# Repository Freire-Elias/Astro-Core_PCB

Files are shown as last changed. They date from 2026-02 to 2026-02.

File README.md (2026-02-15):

# Astro-Core PCB

Placa de controle baseada em **ESP32**, projetada para a equipe de robótica competitiva OBR **AstroTech**.

---

## What is this project?

This project was designed to create a central module for sensors, control, motors, and monitoring of an OBR robot.
This repository contains all the hardware files (PCB and schematics) for this board.

---

## 3D Board Render

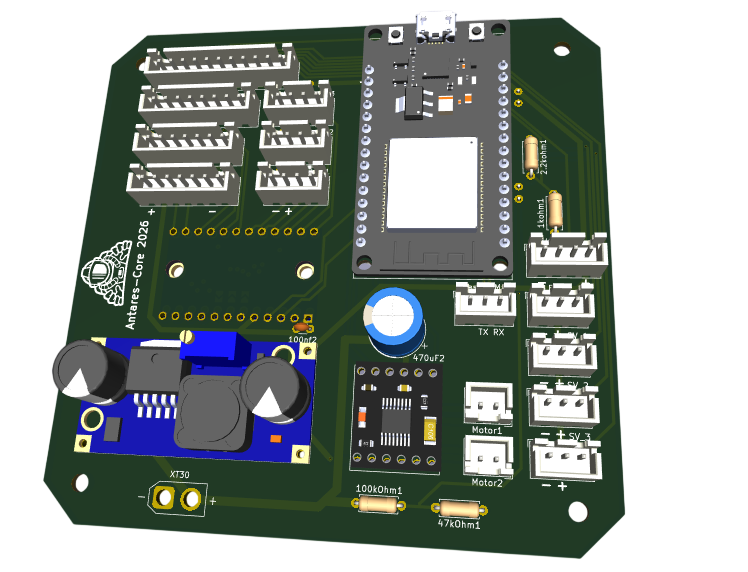
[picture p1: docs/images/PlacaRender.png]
PCB 3D Render


---

## Board Schematic

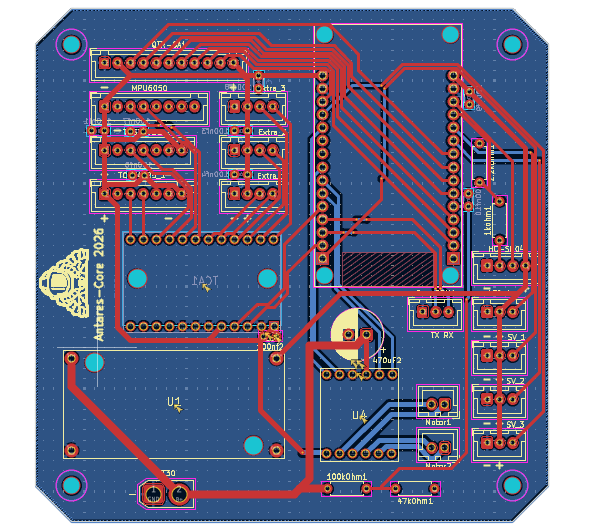
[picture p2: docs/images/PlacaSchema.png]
Schematic


---

## License

This project is under license **MIT**.  
See [LICENSE](LICENSE) for more details.

---

## 👤 Author

Created by **Elias Freire**  
GitHub: https://github.com/Freire-Elias

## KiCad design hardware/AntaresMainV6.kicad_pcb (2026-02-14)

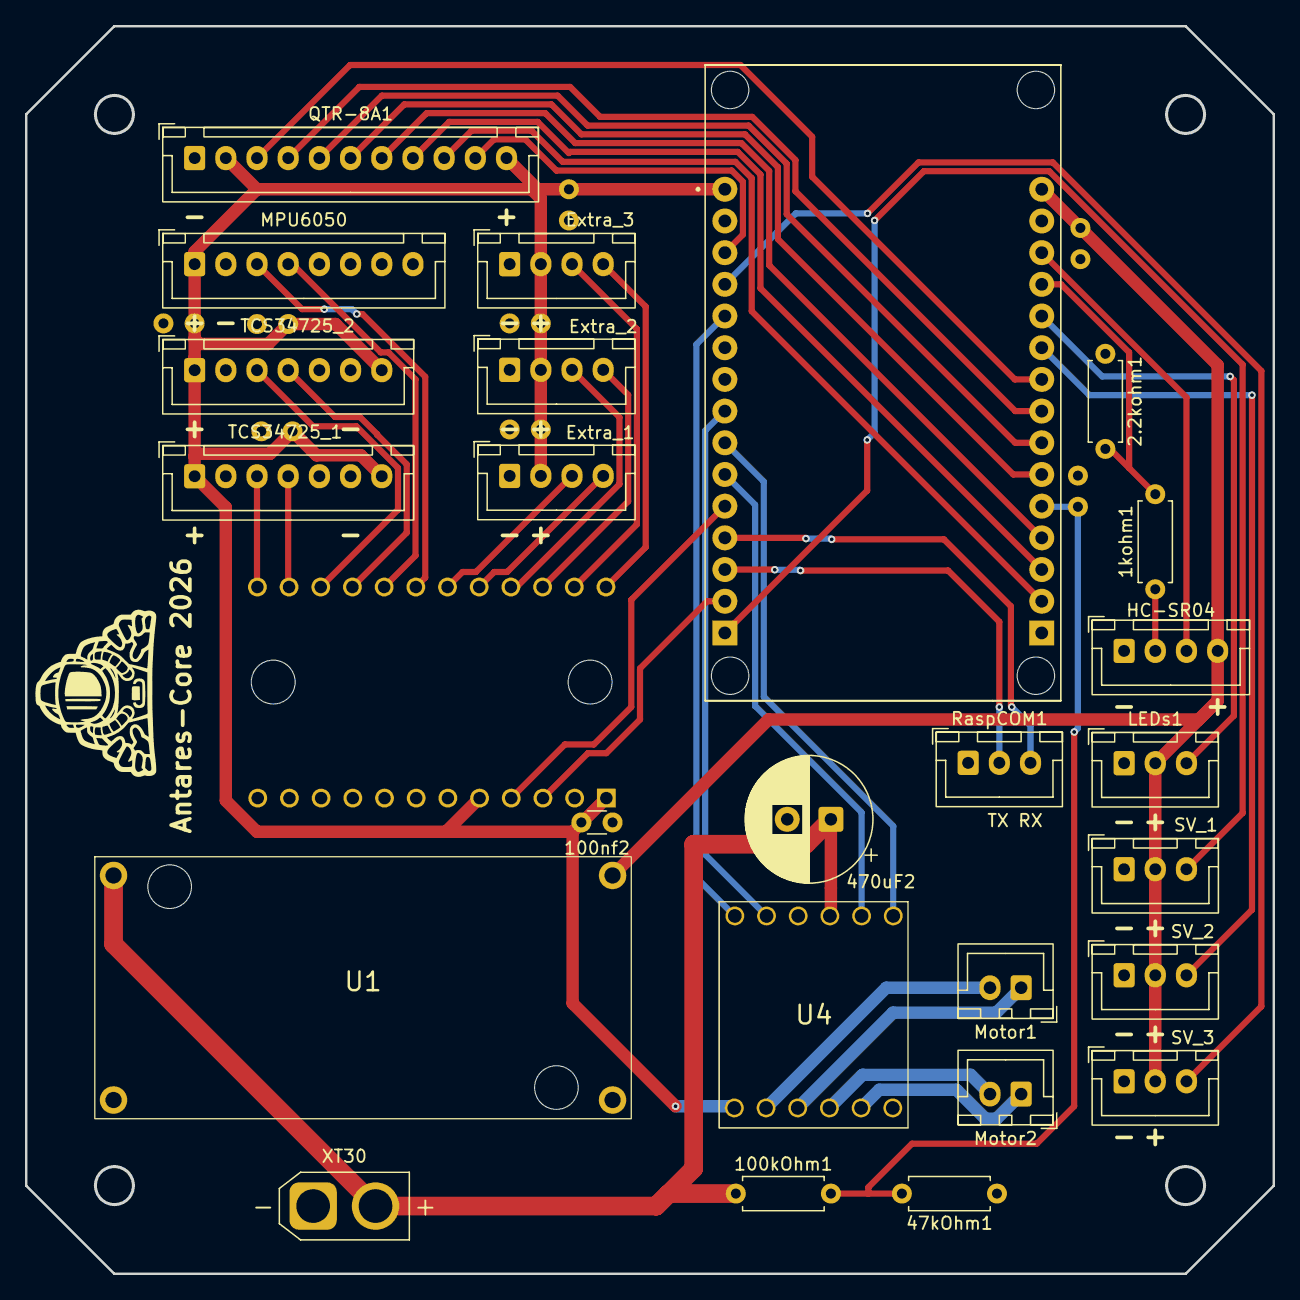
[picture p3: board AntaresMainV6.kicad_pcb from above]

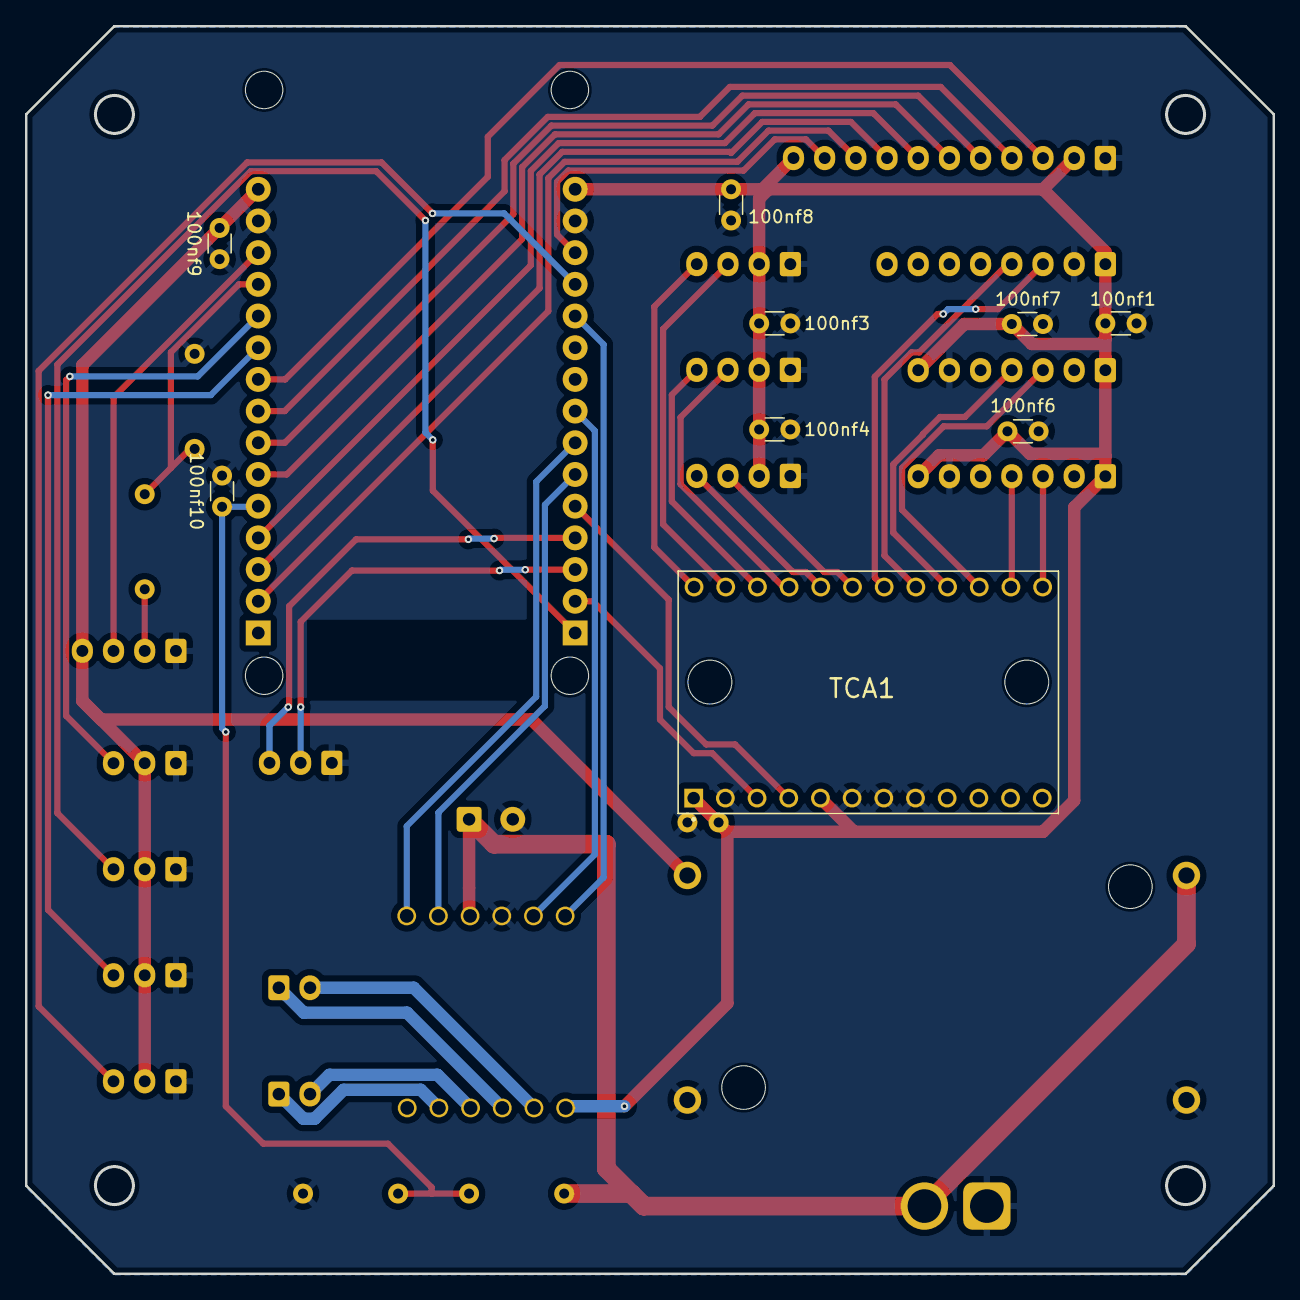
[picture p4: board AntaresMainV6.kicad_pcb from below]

Board: 2 copper layers, 100.0 x 100.0 mm, 35 parts (9 on the bottom side), 44 nets.

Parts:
1kohm1, 2.2kohm1, 47kOhm1, 100kOhm1: R; R_Axial_DIN0207_L6.3mm_D2.5mm_P7.62mm_Horizontal
100nf1, 100nf2, 100nf3, 100nf4, 100nf6, 100nf7, 100nf8, 100nf9, 100nf10: C; C_Disc_D3.0mm_W1.6mm_P2.50mm
470uF2: C_Polarized; CP_Radial_D10.0mm_P3.50mm
Astro: LOGO; PCBIcon
Extra_1, Extra_2, Extra_3: Conn_01x04_Socket; JST_XH_B4B-XH-A_1x04_P2.50mm_Vertical
HC-SR04: Conn_01x04_Socket; JST_XH_B4B-XH-A_1x04_P2.50mm_Vertical
LEDs1: Conn_01x03_Socket; JST_XH_B3B-XH-A_1x03_P2.50mm_Vertical
MPU6050: Conn_01x08_Socket; JST_XH_B8B-XH-A_1x08_P2.50mm_Vertical
Motor1, Motor2: Conn_01x02_Socket; JST_XH_B2B-XH-A_1x02_P2.50mm_Vertical
QTR-8A1: Conn_01x11_Socket; JST_XH_B11B-XH-A_1x11_P2.50mm_Vertical
RaspCOM1: Conn_01x03_Socket; JST_XH_B3B-XH-A_1x03_P2.50mm_Vertical
SV_1, SV_2, SV_3: Conn_01x03_Socket; JST_XH_B3B-XH-A_1x03_P2.50mm_Vertical
TCA1: 2717; TCA9548_ALT
TCS34725_1, TCS34725_2: Conn_01x07_Socket; JST_XH_B7B-XH-A_1x07_P2.50mm_Vertical
U1: Lm2596 DC-DC Buck; Lm2596_ALT
U3: ESP32-DEVKIT-V1; MODULE_ESP32_DEVKIT_V1
U4: DRV8833
XT30: Conn_01x02_Socket; AMASS_XT30U-M_1x02_P5.0mm_Vertical

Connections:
/0+: 100kOhm1.1, 470uF2.1, U1.in+ (IN+), U4.4 (VCC), XT30.2
/3.3v: 100nf1.1, 100nf2.2, 100nf3.1, 100nf4.1, 100nf6.1, 100nf7.2, 100nf8.1, Extra_1.2, Extra_2.2, Extra_3.2, MPU6050.1, QTR-8A1.2, QTR-8A1.11, TCA1.RST, TCA1.VIN, TCS34725_1.1, TCS34725_1.7, TCS34725_2.1, TCS34725_2.7, U3.3V3, U4.7 (EEP)
/5V_LM: 100nf9.2, HC-SR04.4, LEDs1.2, SV_1.2, SV_2.2, SV_3.2, U1.out+ (OUT+), U3.VIN
/BAT: 47kOhm1.2, 100kOhm1.2, 100nf10.1, U3.35 (D35)
/Echo3.3v: 1kohm1.2, 2.2kohm1.2, U3.12 (D12)
/Echo5v: 1kohm1.1, HC-SR04.2
/IN1: U3.4 (D4), U4.1 (IN1)
/IN2: U3.5 (D5), U4.2 (IN2)
/IN3: U3.19 (D19), U4.5 (IN3)
/IN4: U3.18 (D18), U4.6 (IN4)
/LED: LEDs1.3, U3.14 (D14)
/Motors/OUT1: Motor1.2, U4.8 (OUT1)
/Motors/OUT2: Motor1.1, U4.9 (OUT2)
/Motors/OUT3: Motor2.2, U4.10 (OUT3)
/Motors/OUT4: Motor2.1, U4.11 (OUT4)
/Multiplexers/SCL_5: Extra_1.4, TCA1.SC5 (SCL5)
/Multiplexers/SCL_6: Extra_2.4, TCA1.SC6 (SCL6)
/Multiplexers/SCL_7: Extra_3.4, TCA1.SC7 (SCL7)
/Multiplexers/SCL_IMU: MPU6050.3, TCA1.SC4 (SCL4)
/Multiplexers/SCL_S1: TCA1.SC2 (SCL2), TCS34725_1.4
/Multiplexers/SCL_S2: TCA1.SC3, TCS34725_2.4
/Multiplexers/SDA_5: Extra_1.3, TCA1.SD5 (SDA5)
/Multiplexers/SDA_6: Extra_2.3, TCA1.SD6 (SDA6)
/Multiplexers/SDA_7: Extra_3.3, TCA1.SD7 (SDA7)
/Multiplexers/SDA_IMU: MPU6050.4, TCA1.SD4 (SDA4)
/Multiplexers/SDA_S1: TCA1.SD2 (SDA2), TCS34725_1.3
/Multiplexers/SDA_S2: TCA1.SD3 (SDA3), TCS34725_2.3
/OUT1: QTR-8A1.3, U3.26 (D26)
/OUT2: QTR-8A1.4, U3.25 (D25)
/OUT3: QTR-8A1.5, U3.33 (D33)
/OUT4: QTR-8A1.6, U3.32 (D32)
/OUT5: QTR-8A1.7, U3.34 (D34)
/OUT6: QTR-8A1.8, U3.VN
/OUT7: QTR-8A1.9, U3.VP
/OUT8: QTR-8A1.10, U3.15 (D15)
/RX: RaspCOM1.3, U3.RX0
/SCL: TCA1.SCL, U3.21 (D21)
/SDA: TCA1.SDA, U3.22 (D22)
/SV_1: SV_1.3, U3.23 (D23)
/SV_2: SV_2.3, U3.27 (D27)
/SV_3: SV_3.3, U3.2 (D2)
/TX: RaspCOM1.2, U3.TX0
/Trig: HC-SR04.3, U3.13 (D13)
GND: 2.2kohm1.1, 47kOhm1.1, 100nf1.2, 100nf2.1, 100nf3.2, 100nf4.2, 100nf6.2, 100nf7.1, 100nf8.2, 100nf9.1, 100nf10.2, 470uF2.2, Extra_1.1, Extra_2.1, Extra_3.1, HC-SR04.1, LEDs1.1, MPU6050.2, QTR-8A1.1, RaspCOM1.1, SV_1.1, SV_2.1, SV_3.1, TCA1.A0, TCA1.A1, TCA1.A2, TCA1.GND, TCS34725_1.6, TCS34725_2.6, U1.in- (IN-), U1.out- (OUT-), U3.GND, U4.3 (GND), XT30.1

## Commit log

2026-02-03 commit inicial
    [Alimentação.kicad_sch, AntaresMainV6.kicad_pcb, AntaresMainV6.kicad_sch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]
2026-02-05 Mudanças nos footprints
    [Alimentação.kicad_sch, AntaresMainV6.kicad_pcb, AntaresMainV6.kicad_sch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]
2026-02-08 placa semi pronta
    [Alimentação.kicad_sch, AntaresMainV6.kicad_pcb, AntaresMainV6.kicad_sch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]
2026-02-09 Modificações semi finais
    [Alimentação.kicad_sch, AntaresMainV6.kicad_pcb, AntaresMainV6.kicad_sch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]
2026-02-09 Faltando apenas LED e verificação
    [AntaresMainV6.kicad_pcb]
2026-02-10 Decisão final da multiplexadora
    [AntaresMainV6.kicad_pcb, AntaresMainV6.kicad_sch]
2026-02-10 Remoção da mux
    [AntaresMainV6.kicad_pcb, AntaresMainV6.kicad_sch, Multiplexers.kicad_sch]
2026-02-12 erros ajustados e placa reformulada
    [Alimentação.kicad_sch, AntaresMainV6.kicad_pcb, AntaresMainV6.kicad_sch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]
2026-02-14 Placa Finalizada
    [Alimentação.kicad_sch, AntaresMainV6.kicad_pcb, AntaresMainV6.kicad_sch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]
